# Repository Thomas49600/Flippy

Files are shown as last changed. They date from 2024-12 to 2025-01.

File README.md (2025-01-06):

# Flippy
Introducing Flippy! The all-in-one modular 3D printed electromechanical seven-segment display. Through the use of 14 electromagnets, each digit is able to quickly and mechanically display both numbers and letters. This creates a unique and satisfying display.

To build your own, check the full build instructions on Instructables: https://www.instructables.com/3D-Printed-Electromechanical-7-Segment-Display/

Or watch the YouTube video below (Link: https://youtu.be/np4NRMKOG6U)

Video Title (https://www.youtube.com/watch?v=np4NRMKOG6U)

This project falls under the CC BY-NC-SA 4.0 Licence

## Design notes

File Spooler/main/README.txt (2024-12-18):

This code was written within an hour, it is not perfect, nor is it well commented. To modify the number of windings, edit line 5:

#define TOTAL_WINDINGS 1885 //total number of loops of copper wire

You will need to experiment with this value until it results in a coil with the correct resistance.
If you are a programmer, please feel free to rewrite this code... and even share it so others can use it!

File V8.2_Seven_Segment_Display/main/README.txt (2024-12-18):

This is V8.2 of a mechanical seven-segment designed to display both words and numbers in an attractive and interesting way.
This code supports up to 8 digits and has room for expansion in the future

To upload this code do the following:
> Hold down the "flash" button on your NodeMCU
> Plug the USB connector into your computer and NodeMCU
> Wait 3 seconds
> Release the "flash" button

> Open wifi.cpp in a text editor and add your local wifi details on line 67 of wifi.cpp (make sure they are 2.4g)
> Open main.ino in Arduino IDE then compile + upload it using Arduino IDE or similar
	> Watch the following video (Credit to Brian Lough) on how to install Arduino IDE, the ESP8266 Software and the required drivers
		> https://www.youtube.com/watch?v=AFUAMVFzpWw

	> Choose the board "NodeMCU 1.0 (ESP-12E Module)"
	> Under "Tools" (top menu) choose "Flash Size - 4MB (FS:3MB OTA:~512KB)" and "Upload Speed: 115200"
	> Then hit upload (arrow button ->)

After uploading the code you will need to upload the file system
> Follow the instructions listed on this page to install the file system plugin (this is for Arduino IDE 2.2.1 or higher)
	> https://github.com/earlephilhower/arduino-littlefs-upload (Credit to earlephilhower)

> There are unfortunately a few bugs with this plugin
	> If you attempt to upload and it says "Please compile this sketch at least once", select a random board and attempt to upload the files (it will fail) then go back to your NodeMCU board and try again (it should work)
	> If you get a file path "Undefined" when you attempt to upload, close and re-open your sketch
	> If it says it cannot open serial port <port>, make sure you have closed serial monitor in all instances of Arduino IDE

> Ensure you are connected to your NodeMCU via USB and the NodeMCU is running normally (this will also likely require 12V to be plugged into the main PCB and the common anode digit connector to be disconnected)
> Then simply press [Ctrl] + [Shift] + [P], then "Upload LittleFS to Pico/ESP8266/ESP32"

After restarting your NodeMCU (either by disconnecting and reconnecting power or the RST button) you can now access the main page at "flippy.local" in a web browser on the same wifi network as you connected the device to
Sometimes due to lag the pages may fail to properly load, if this happens, refresh the webpage and it should work.
The webpages are intended for computers so if you wish to use them on your phone, simply select "desktop site" in your browser.

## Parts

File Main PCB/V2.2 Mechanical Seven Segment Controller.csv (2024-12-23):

Id | Designator | Footprint | Quantity | Designation | Supplier and ref
1 | R3,R2 | R_Axial_DIN0207_L6.3mm_D2.5mm_P7.62mm_Horizontal | 2 | 10k
2 | U6,U4,U2 | 16_Pin_DIL_IC_Socket | 3 | 74HC595
3 | K4,K2,K8,K5,K1,K3,K6,K7 | Relay_SPST_Altronics_S4252B | 8 | Relay 12V DC
4 | C6,C7,C8,C9,C5,C4,C2,C10 | C_Disc_D4.3mm_W1.9mm_P5.00mm | 8 | 0.1uf
5 | J11 | 3_Way_Screw_Terminal_Altronics_(P2033B) | 1 | MAIN POWER TERMINAL
6 | U3,U1,U5 | 18_Pin_DIL_IC_Socket | 3 | ULN2803A
7 | D3,D4,D1,D2,D7,D5,D6,D8 | D_DO-41_SOD81_P10.16mm_Horizontal | 8 | 1N4004
8 | ,,, |  | 4
9 | F1 | PinHeader_1x02_P2.54mm_Vertical | 1 | Fuse
10 | U7 | TO255P1020X450X1968-3 | 1 | LD1117V33
11 | A1 | SEEED_113990105 | 1 | Node MCU ESP8266
12 | J8 | PinHeader_1x08_P2.54mm_Vertical | 1 | Digit Connectors (+ve)
13 | J4 | PinHeader_1x03_P2.54mm_Vertical | 1 | Spare 3.3V
14 | C3 | CP_Radial_D5.0mm_P2.00mm | 1 | 10uf
15 | J9,J6 | PinHeader_1x15_P2.54mm_Vertical | 2 | ESP8266 Extra Pins
16 | J10 | PinHeader_1x05_P2.54mm_Vertical | 1 | Shift Register Expantion Ports
17 | R1 | R_Axial_DIN0207_L6.3mm_D2.5mm_P7.62mm_Horizontal | 1 | 220
18 | J7 | PinHeader_1x08_P2.54mm_Vertical | 1 | White Seg Conn (-ve)
19 | J1 | PinHeader_1x03_P2.54mm_Vertical | 1 | Spare GND
20 | J5 | PinHeader_1x08_P2.54mm_Vertical | 1 | Black Seg Conn (-ve)
21 | J2 | PinHeader_1x03_P2.54mm_Vertical | 1 | Spare VDC
22 | D9 | LED_D5.0mm | 1 | PWR_LED
23 | C1 | CP_Radial_D10.0mm_P5.00mm | 1 | 100uf
24 | J3 | PinHeader_1x03_P2.54mm_Vertical | 1 | Spare 5V

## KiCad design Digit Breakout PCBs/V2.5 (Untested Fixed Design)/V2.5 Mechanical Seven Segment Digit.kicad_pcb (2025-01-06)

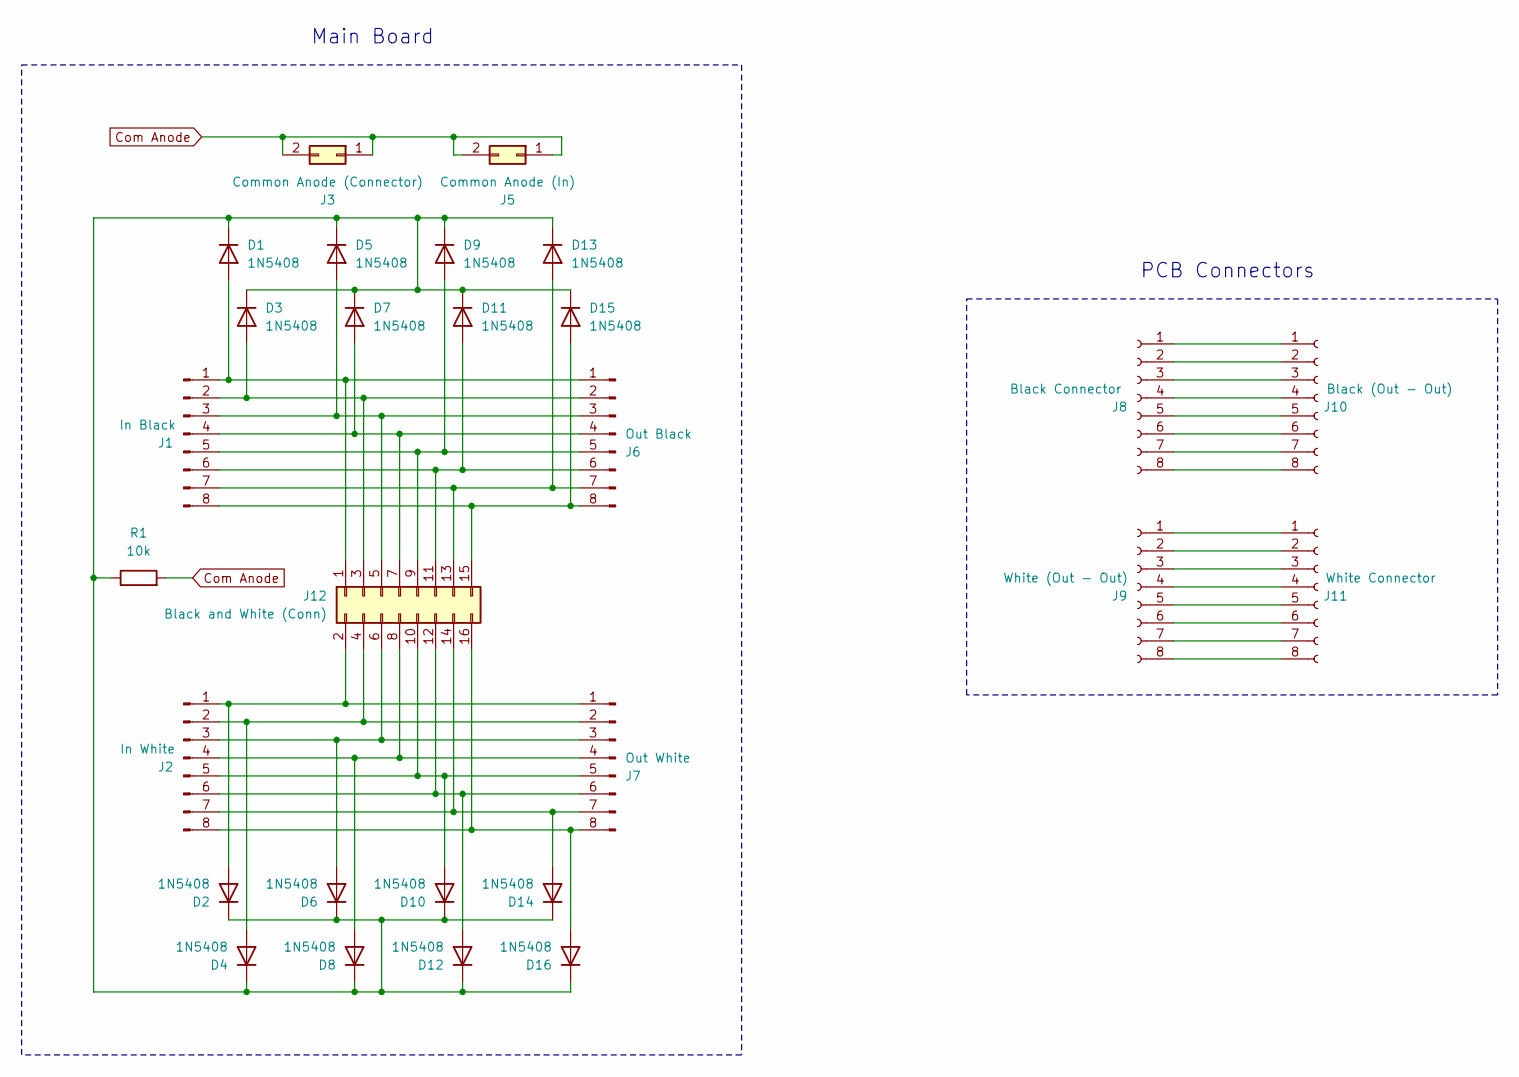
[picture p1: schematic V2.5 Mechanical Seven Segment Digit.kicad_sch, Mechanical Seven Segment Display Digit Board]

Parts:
D1, D2, D3, D4, D5, D6, D7, D8, D9, D10, D11, D12, D13, D14, D15, D16: 1N5408; D_DO-201AD_P15.24mm_Horizontal
J1: In Black; PinSocket_1x08_P2.54mm_Vertical
J2: In White; PinSocket_1x08_P2.54mm_Vertical
J3: Common Anode (Connector); PinSocket_2x01_P2.54mm_Vertical
J5: Common Anode (In); PinSocket_2x01_P2.54mm_Vertical
J6: Out Black; PinSocket_1x08_P2.54mm_Vertical
J7: Out White; PinSocket_1x08_P2.54mm_Vertical
J8: Black Connector; PinSocket_1x08_P2.54mm_Vertical
J9: White (Out - Out); PinSocket_1x08_P2.54mm_Vertical
J10: Black (Out - Out); PinSocket_1x08_P2.54mm_Vertical
J11: White Connector; PinSocket_1x08_P2.54mm_Vertical
J12: Black and White (Conn); PinSocket_2x08_P2.54mm_Vertical
R1: 10k; R_Axial_DIN0207_L6.3mm_D2.5mm_P7.62mm_Horizontal

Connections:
Com Anode: J3.1, J3.2, J5.1, J5.2, R1.2
unnamed: D1.2 (A), J1.1, J6.1, J12.1
unnamed: D1.1 (K), D2.1 (K), D3.1 (K), D4.1 (K), D5.1 (K), D6.1 (K), D7.1 (K), D8.1 (K), D9.1 (K), D10.1 (K), D11.1 (K), D12.1 (K), D13.1 (K), D14.1 (K), D15.1 (K), D16.1 (K), R1.1
unnamed: D2.2 (A), J2.1, J7.1, J12.2
unnamed: D3.2 (A), J1.2, J6.2, J12.3
unnamed: D4.2 (A), J2.2, J7.2, J12.4
unnamed: D5.2 (A), J1.3, J6.3, J12.5
unnamed: D6.2 (A), J2.3, J7.3, J12.6
unnamed: D7.2 (A), J1.4, J6.4, J12.7
unnamed: D8.2 (A), J2.4, J7.4, J12.8
unnamed: D9.2 (A), J1.5, J6.5, J12.9
unnamed: D10.2 (A), J2.5, J7.5, J12.10
unnamed: D11.2 (A), J1.6, J6.6, J12.11
unnamed: D12.2 (A), J2.6, J7.6, J12.12
unnamed: D13.2 (A), J1.7, J6.7, J12.13
unnamed: D14.2 (A), J2.7, J7.7, J12.14
unnamed: D15.2 (A), J1.8, J6.8, J12.15
unnamed: D16.2 (A), J2.8, J7.8, J12.16
unnamed: J8.1, J10.1
unnamed: J8.2, J10.2
unnamed: J8.3, J10.3
unnamed: J8.4, J10.4
unnamed: J8.5, J10.5
unnamed: J8.6, J10.6
unnamed: J8.7, J10.7
unnamed: J8.8, J10.8
unnamed: J9.1, J11.1
unnamed: J9.2, J11.2
unnamed: J9.3, J11.3
unnamed: J9.4, J11.4
unnamed: J9.5, J11.5
unnamed: J9.6, J11.6
unnamed: J9.7, J11.7
unnamed: J9.8, J11.8

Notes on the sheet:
Main Board
PCB Connectors

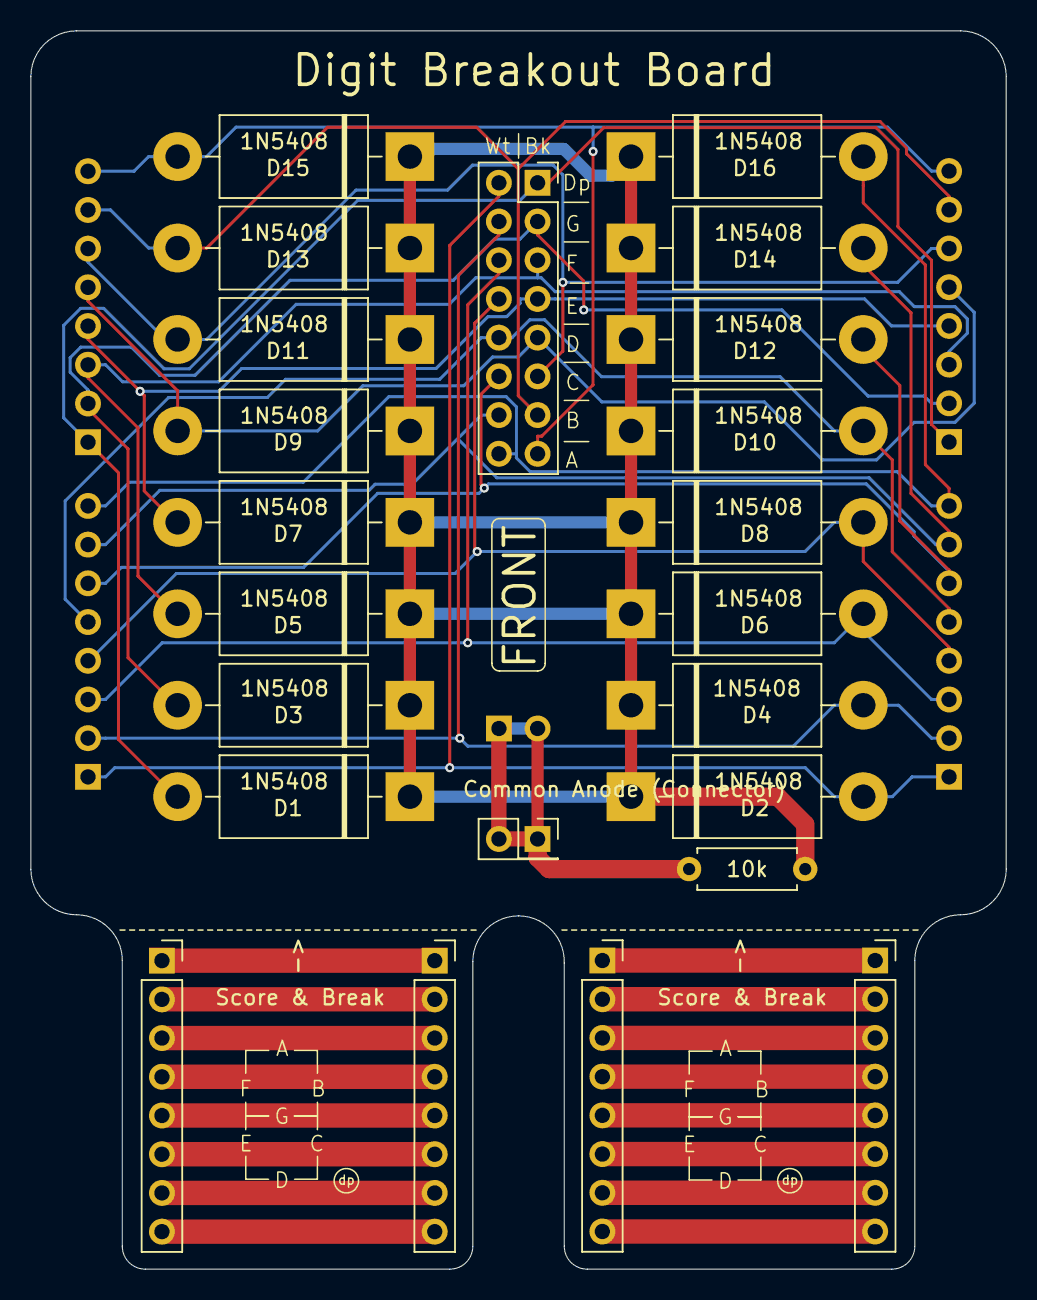
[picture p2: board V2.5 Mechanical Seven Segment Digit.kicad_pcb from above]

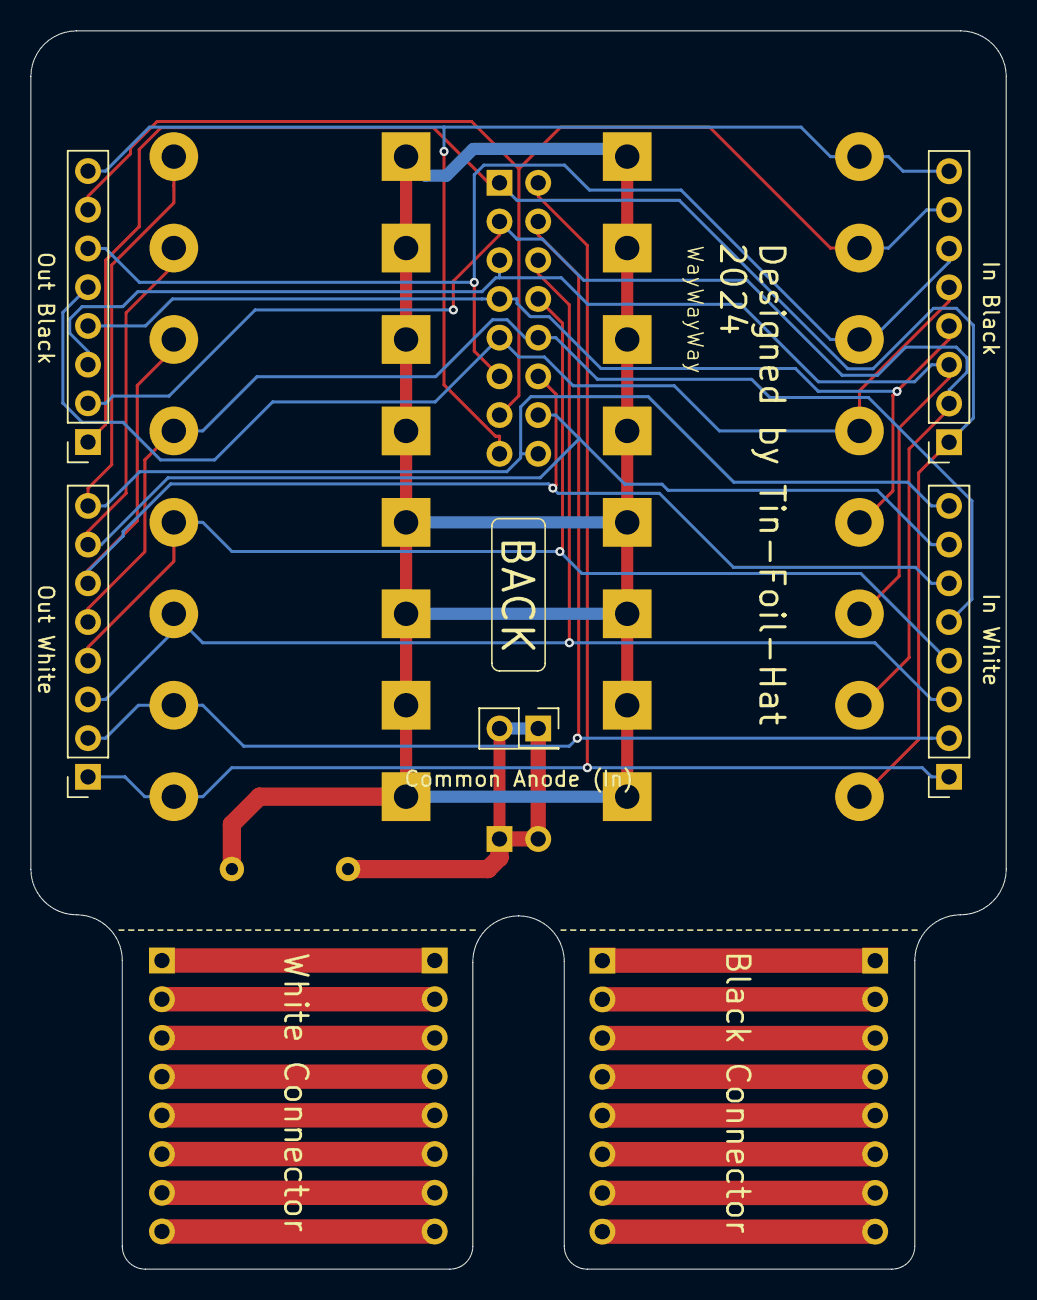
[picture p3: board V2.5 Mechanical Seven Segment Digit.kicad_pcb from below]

Board: 2 copper layers, 64.0 x 81.3 mm, 28 parts (5 on the bottom side), 34 nets.

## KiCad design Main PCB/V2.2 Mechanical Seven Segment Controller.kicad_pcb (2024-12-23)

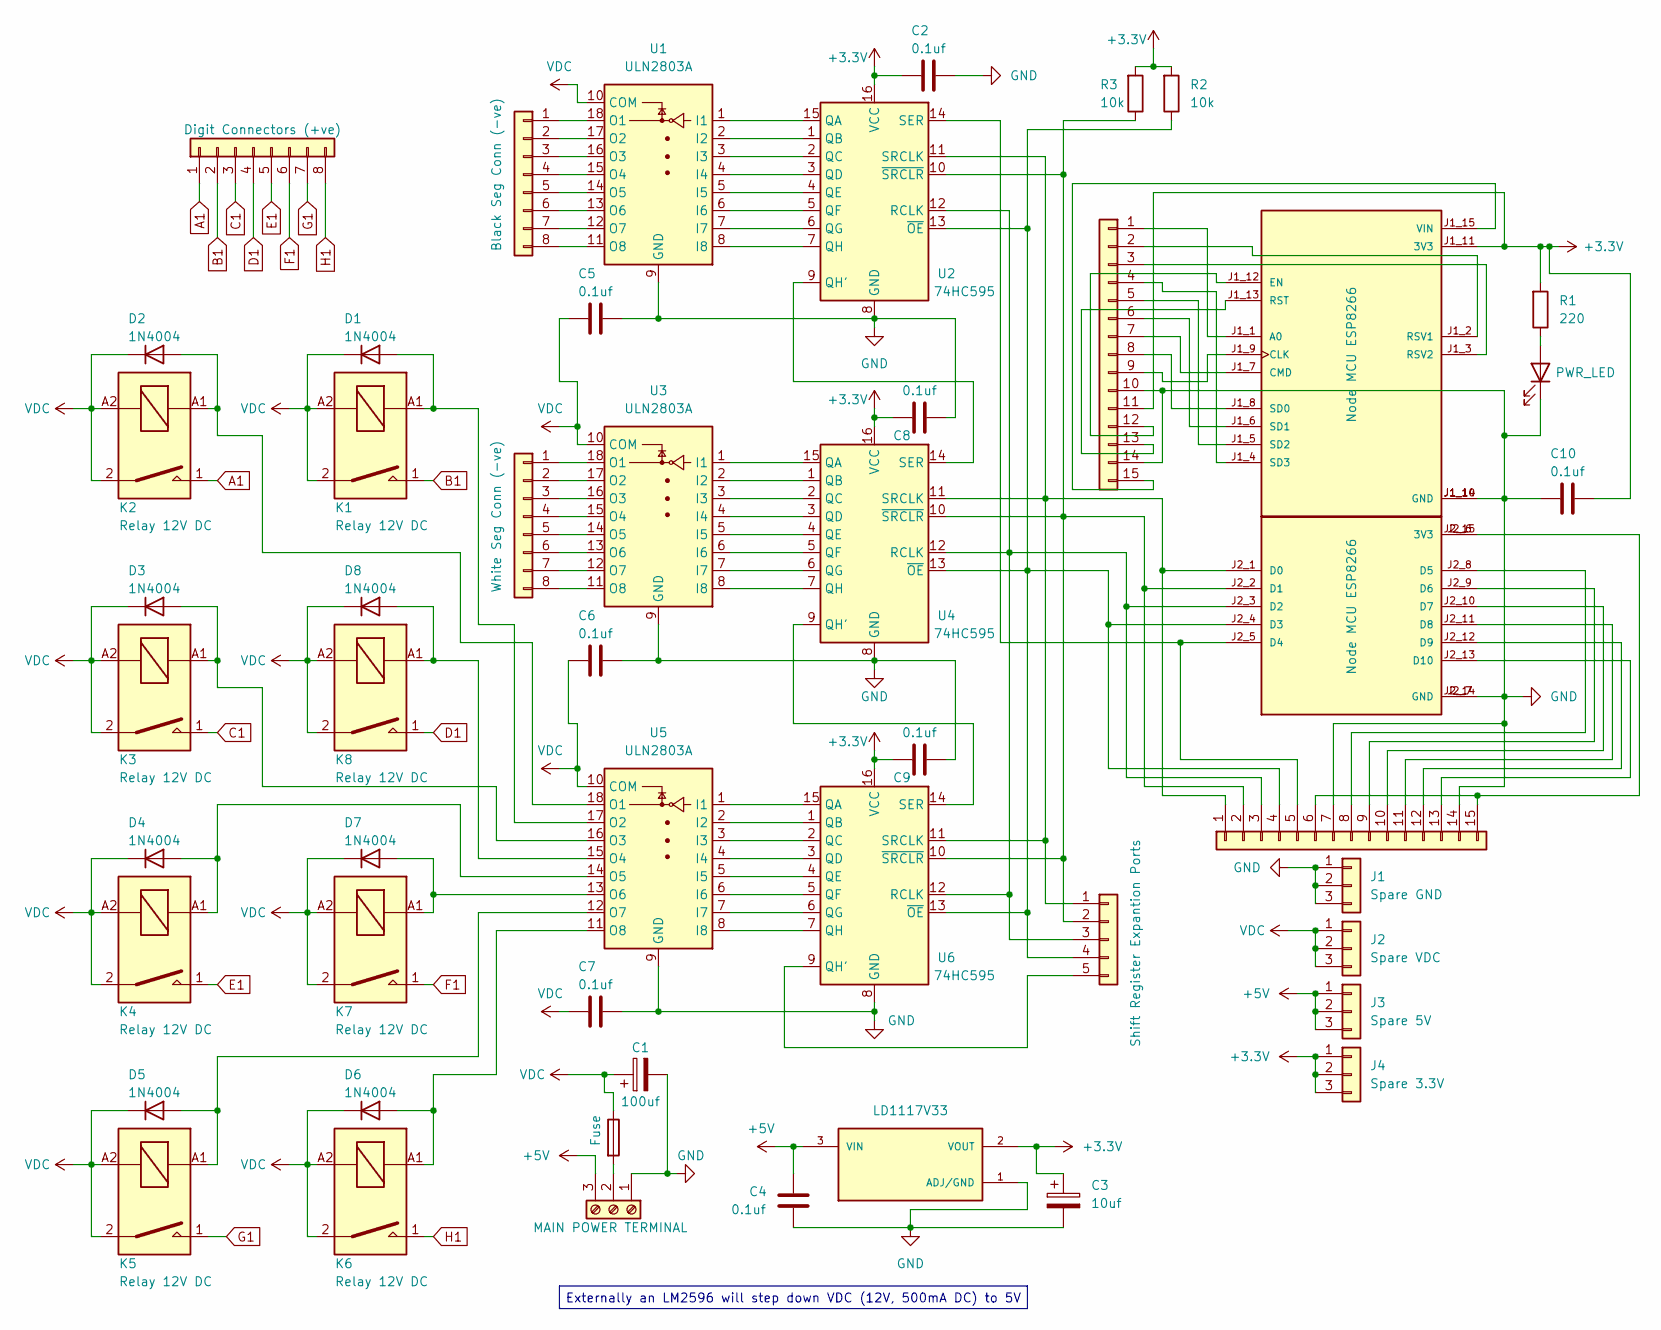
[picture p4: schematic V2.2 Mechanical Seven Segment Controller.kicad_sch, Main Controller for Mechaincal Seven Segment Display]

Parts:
A1: Node MCU ESP8266; SEEED_113990105; PARTREV N/A
C1: 100uf; CP_Radial_D10.0mm_P5.00mm
C2, C4, C5, C6, C7, C8, C9, C10: 0.1uf; C_Disc_D4.3mm_W1.9mm_P5.00mm
C3: 10uf; CP_Radial_D5.0mm_P2.00mm
D1, D2, D3, D4, D5, D6, D7, D8: 1N4004; D_DO-41_SOD81_P10.16mm_Horizontal
D9: PWR_LED; LED_D5.0mm
F1: Fuse; PinHeader_1x02_P2.54mm_Vertical
J1: Spare GND; PinHeader_1x03_P2.54mm_Vertical
J2: Spare VDC; PinHeader_1x03_P2.54mm_Vertical
J3: Spare 5V; PinHeader_1x03_P2.54mm_Vertical
J4: Spare 3.3V; PinHeader_1x03_P2.54mm_Vertical
J5: Black Seg Conn (-ve); PinHeader_1x08_P2.54mm_Vertical
J6, J9: ESP8266 Extra Pins; PinHeader_1x15_P2.54mm_Vertical
J7: White Seg Conn (-ve); PinHeader_1x08_P2.54mm_Vertical
J8: Digit Connectors (+ve); PinHeader_1x08_P2.54mm_Vertical
J10: Shift Register Expantion Ports; PinHeader_1x05_P2.54mm_Vertical
J11: MAIN POWER TERMINAL; 3_Way_Screw_Terminal_Altronics_(P2033B)
K1, K2, K3, K4, K5, K6, K7, K8: Relay 12V DC; Relay_SPST_Altronics_S4252B
R1: 220; R_Axial_DIN0207_L6.3mm_D2.5mm_P7.62mm_Horizontal
R2, R3: 10k; R_Axial_DIN0207_L6.3mm_D2.5mm_P7.62mm_Horizontal
U1, U3, U5: ULN2803A; 18_Pin_DIL_IC_Socket
U2, U4, U6: 74HC595; 16_Pin_DIL_IC_Socket
U7: LD1117V33; TO255P1020X450X1968-3; PARTREV 37

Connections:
+3.3V: A1.J1_11 (3V3), C2.2, C3.1, C8.2, C9.2, C10.1, J4.1, J4.2, J4.3, J6.11, R1.2, R2.2, R3.2, U2.16 (VCC), U4.16 (VCC), U6.16 (VCC), U7.2 (VOUT)
+5V: C4.1, J3.1, J3.2, J3.3, J11.3, U7.3 (VIN)
A1: J8.1, K2.1
B1: J8.2, K1.1
C1: J8.3, K3.1
D1: J8.4, K8.1
E1: J8.5, K4.1
F1: J8.6, K7.1
G1: J8.7, K5.1
GND: A1.J1_10 (GND), A1.J1_14 (GND), A1.J2_7 (GND), A1.J2_14 (GND), C1.2, C2.1, C3.2, C4.2, C5.1, C6.1, C7.1, C8.1, C9.1, C10.2, D9.1 (K), J1.1, J1.2, J1.3, J6.10, J6.14, J9.7, J9.14, J11.1, U1.9 (GND), U2.8 (GND), U3.9 (GND), U4.8 (GND), U5.9 (GND), U6.8 (GND), U7.1 (ADJ/GND)
H1: J8.8, K6.1
unnamed: A1.J1_1 (A0), J6.1
unnamed: A1.J1_9 (CLK), J6.9
unnamed: A1.J1_7 (CMD), J6.7
unnamed: A1.J1_12 (EN), J6.12
unnamed: A1.J1_13 (RST), J6.13
unnamed: A1.J1_2 (RSV1), J6.2
unnamed: A1.J1_3 (RSV2), J6.3
unnamed: A1.J1_8 (SD0), J6.8
unnamed: A1.J1_6 (SD1), J6.6
unnamed: A1.J1_5 (SD2), J6.5
unnamed: A1.J1_4 (SD3), J6.4
unnamed: A1.J1_15 (VIN), J6.15
unnamed: A1.J2_1 (D0), J9.1, J10.1, U2.11 (SRCLK), U4.11 (SRCLK), U6.11 (SRCLK)
unnamed: A1.J2_2 (D1), J9.2, J10.2, R3.1, U2.10 (~SRCLR), U4.10 (~SRCLR), U6.10 (~SRCLR)
unnamed: A1.J2_3 (D2), J9.3, J10.3, U2.12 (RCLK), U4.12 (RCLK), U6.12 (RCLK)
unnamed: A1.J2_4 (D3), J9.4, J10.4, R2.1, U2.13 (~OE), U4.13 (~OE), U6.13 (~OE)
unnamed: A1.J2_5 (D4), J9.5, U2.14 (SER)
unnamed: A1.J2_8 (D5), J9.8
unnamed: A1.J2_9 (D6), J9.9
unnamed: A1.J2_10 (D7), J9.10
unnamed: A1.J2_11 (D8), J9.11
unnamed: A1.J2_12 (D9), J9.12
unnamed: A1.J2_13 (D10), J9.13
unnamed: D1.2 (A), K1.A1, U5.17 (O2)
unnamed: D2.2 (A), K2.A1, U5.18 (O1)
unnamed: D3.2 (A), K3.A1, U5.16 (O3)
unnamed: D4.2 (A), K4.A1, U5.14 (O5)
unnamed: D5.2 (A), K5.A1, U5.12 (O7)
unnamed: D6.2 (A), K6.A1, U5.11 (O8)
unnamed: D7.2 (A), K7.A1, U5.13 (O6)
unnamed: D8.2 (A), K8.A1, U5.15 (O4)
unnamed: D9.2 (A), R1.1
unnamed: J5.1, U1.18 (O1)
unnamed: J5.2, U1.17 (O2)
unnamed: J5.3, U1.16 (O3)
unnamed: J5.4, U1.15 (O4)
unnamed: J5.5, U1.14 (O5)
unnamed: J5.6, U1.13 (O6)
unnamed: J5.7, U1.12 (O7)
unnamed: J5.8, U1.11 (O8)
unnamed: J7.1, U3.18 (O1)
unnamed: J7.2, U3.17 (O2)
unnamed: J7.3, U3.16 (O3)
unnamed: J7.4, U3.15 (O4)
unnamed: J7.5, U3.14 (O5)
unnamed: J7.6, U3.13 (O6)
unnamed: J7.7, U3.12 (O7)
unnamed: J7.8, U3.11 (O8)
unnamed: A1.J2_6 (3V3), A1.J2_15 (3V3), J9.6, J9.15
unnamed: J10.5, U6.9 (QH')
unnamed: F1.2, J11.2
unnamed: U1.1 (I1), U2.15 (QA)
unnamed: U1.2 (I2), U2.1 (QB)
unnamed: U1.3 (I3), U2.2 (QC)
unnamed: U1.4 (I4), U2.3 (QD)
unnamed: U1.5 (I5), U2.4 (QE)
unnamed: U1.6 (I6), U2.5 (QF)
unnamed: U1.7 (I7), U2.6 (QG)
unnamed: U1.8 (I8), U2.7 (QH)
unnamed: U2.9 (QH'), U4.14 (SER)
unnamed: U3.1 (I1), U4.15 (QA)
unnamed: U3.2 (I2), U4.1 (QB)
unnamed: U3.3 (I3), U4.2 (QC)
unnamed: U3.4 (I4), U4.3 (QD)
unnamed: U3.5 (I5), U4.4 (QE)
unnamed: U3.6 (I6), U4.5 (QF)
unnamed: U3.7 (I7), U4.6 (QG)
unnamed: U3.8 (I8), U4.7 (QH)
unnamed: U4.9 (QH'), U6.14 (SER)
unnamed: U5.1 (I1), U6.15 (QA)
unnamed: U5.2 (I2), U6.1 (QB)
unnamed: U5.3 (I3), U6.2 (QC)
unnamed: U5.4 (I4), U6.3 (QD)
unnamed: U5.5 (I5), U6.4 (QE)
unnamed: U5.6 (I6), U6.5 (QF)
unnamed: U5.7 (I7), U6.6 (QG)
unnamed: U5.8 (I8), U6.7 (QH)
VDC: C1.1, C5.2, C6.2, C7.2, D1.1 (K), D2.1 (K), D3.1 (K), D4.1 (K), D5.1 (K), D6.1 (K), D7.1 (K), D8.1 (K), F1.1, J2.1, J2.2, J2.3, K1.2, K1.A2, K2.2, K2.A2, K3.2, K3.A2, K4.2, K4.A2, K5.2, K5.A2, K6.2, K6.A2, K7.2, K7.A2, K8.2, K8.A2, U1.10 (COM), U3.10 (COM), U5.10 (COM)

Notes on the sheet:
Externally an LM2596 will step down VDC (12V, 500mA DC) to 5V

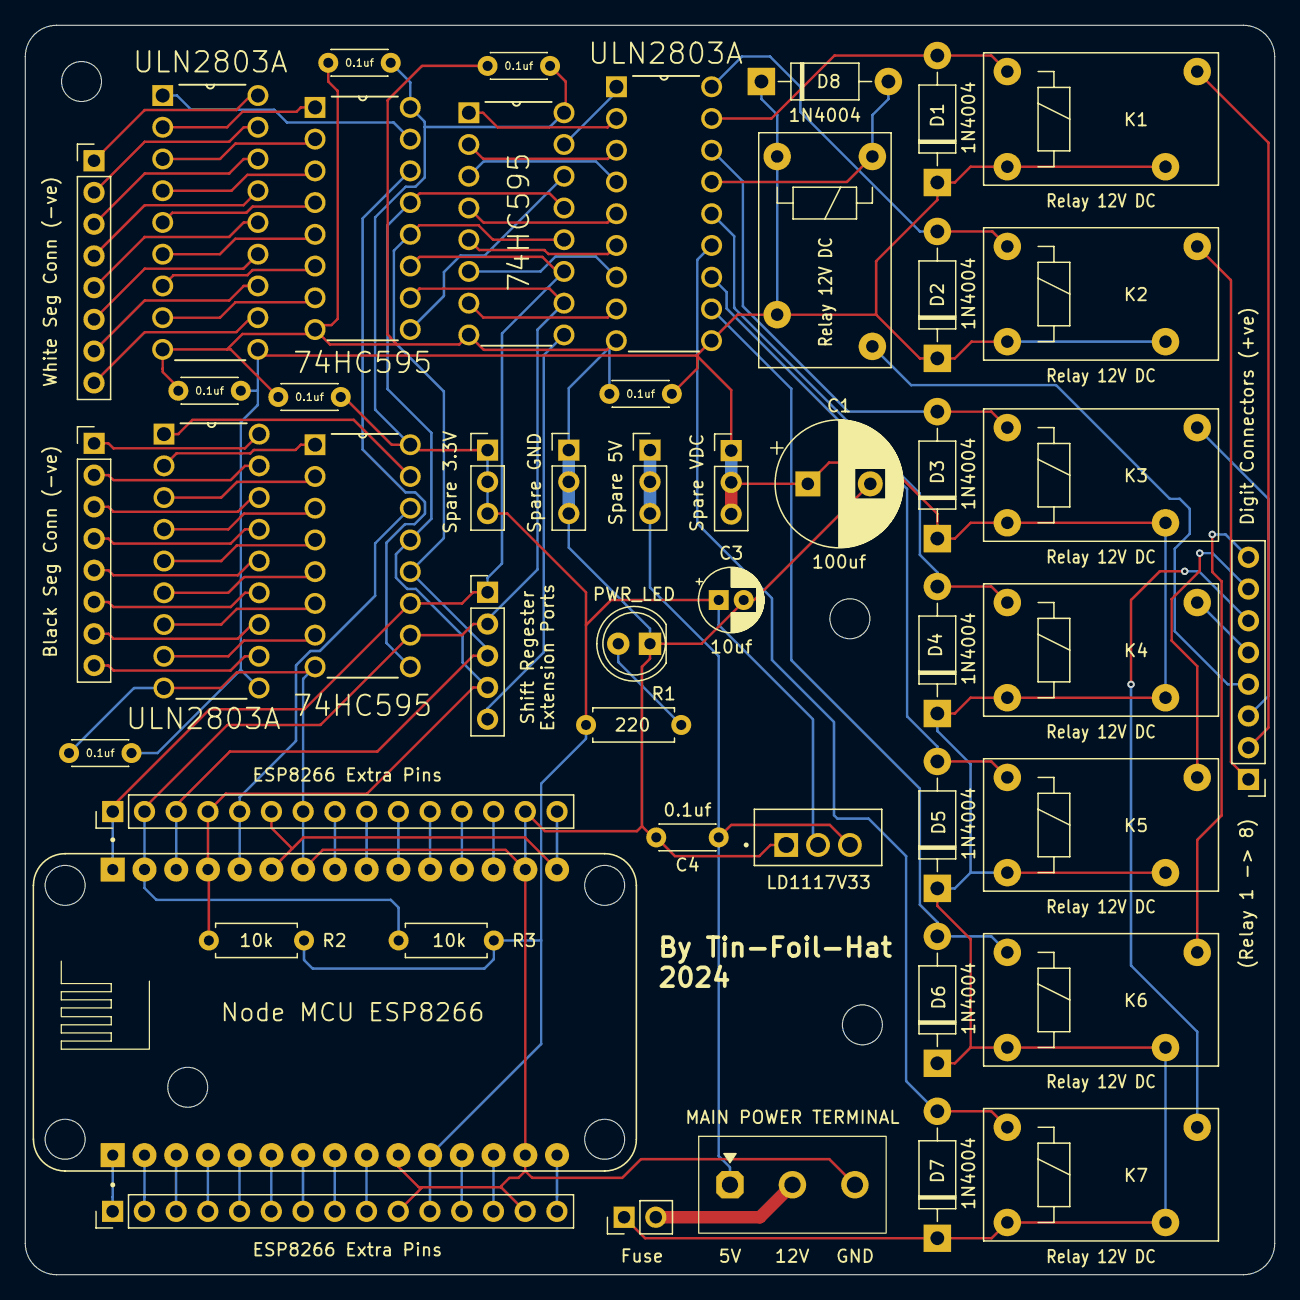
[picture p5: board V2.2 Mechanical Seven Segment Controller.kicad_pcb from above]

Board: 2 copper layers, 100.0 x 100.0 mm, 49 parts (0 on the bottom side), 89 nets.

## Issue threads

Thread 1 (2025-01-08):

Missing drill file in fixed digit board.

mypaxa00, 2025-01-08:
There is no drill file for fixed 2.5 version of digit board. Is it the same as 2.4, or could you please add missing file?

Thomas49600, 2025-01-08:
How do you know they're missing? I tried uploading them to PCBWay and it seemed to work? If you still have issues I'll try uploading all the files again. By drill files do you mean for the THT components or for bolt holes?

mypaxa00, 2025-01-08:
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
I'm not much into pcb manufacturing.
Here is the review response from the PCBWay.

Thomas49600, 2025-01-08:
Ok very odd... I will delete the current files re-export and upload them. I will try uploading the new ones to PCBWay again myself.

Thomas49600, 2025-01-09:
New ones are uploaded! Let me know if you have any issues

mypaxa00, 2025-01-09:
Looks like it is fine now, I was able to order the PCB. Thank you for your support here.

Closed 2025-01-09.

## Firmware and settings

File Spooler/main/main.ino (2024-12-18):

#include <Servo.h>

Servo myservo;

#define TOTAL_WINDINGS 1885 //total number of loops of copper wire
#define MAX_SERVO 86 // adjust to set the max servo angle
#define MIN_SERVO 10 // adjust to set the min servo angle
#define BASE_SERVO_FACTOR 4 // the basic speed of the servo moving

int stepCount = 0; // Counter to keep track of steps
int servoPos = MIN_SERVO; // Starting position of the servo
bool movingDown = true; // Flag to track direction of servo movement

/*
>> Make sure servo and motor are on separate timers <<
Timer0: Pins 5 and 6
Timer1: Pins 9 and 10
Timer2: Pins 3 and 11

The above is for an Arduino UNO
*/

// Define the pin numbers
const int enPin = 11;   // Enable pin for motor
const int in1Pin = 4;   // Input pin 1 for motor
const int in2Pin = 3;   // Input pin 2 for motor
const int irSensorPin = 2; // IR sensor pin

volatile unsigned long pulseCount = 0; // Counter for IR sensor pulses
unsigned long lastPulseTime = 0; // Time of the last detected pulse
unsigned long debounceDelay = 1.5; // Debounce delay in milliseconds

void setup() {
  // Set pin modes
  pinMode(enPin, OUTPUT);
  pinMode(in1Pin, OUTPUT);
  pinMode(in2Pin, OUTPUT);
  pinMode(irSensorPin, INPUT);
  
  // Initialize motor direction
  digitalWrite(in1Pin, HIGH);
  digitalWrite(in2Pin, LOW);
  
  // Attach interrupt to the IR sensor pin
  attachInterrupt(digitalPinToInterrupt(irSensorPin), countPulse, RISING);

  myservo.attach(9); // Attach the servo to pin 9
  myservo.write(MIN_SERVO);
  
  Serial.begin(9600); // Initialize serial communication for debugging
}

float mapFloat(float x, float in_min, float in_max, float out_min, float out_max) {
  return (x - in_min) * (out_max - out_min) / (in_max - in_min) + out_min;
}

void loop() {
  pulseCount = 0; // Reset pulse count

  int delayTime = 6000;
  int steps = 100; // Number of steps to change the speed
  int stepDelay = delayTime / steps; // Time for each step

  // Accelerate to full speed over X seconds
  for (int i = 0; i <= steps; i++) {
    Serial.println(pulseCount);
    int speed = map(i, 0, steps, 40, 255); // Map step to PWM value (min-255)
    analogWrite(enPin, speed); // Set motor speed
    delay(stepDelay); // Wait for the next step

    // Move the servo during acceleration
    if (stepCount % 2 == 0) {
      if (movingDown) {
        servoPos--; // Move the servo down
        if (servoPos <= MIN_SERVO) {
          movingDown = false; // Change direction when reaching MIN_SERVO
        }
      } else {
        servoPos++; // Move the servo up
        if (servoPos >= MAX_SERVO) {
          movingDown = true; // Change direction when reaching MAX_SERVO
        }
      }
      myservo.write(servoPos); // Move the servo to the new position
    }
    stepCount++;
  }

  // Rotate the motor X number of times
  unsigned long targetPulses = TOTAL_WINDINGS - 200;
  while (pulseCount < targetPulses) {
    Serial.println(pulseCount);
    /*
    Serial.print(2);
    Serial.print(", ");
    Serial.print(10);
    Serial.print(", ");
    Serial.println(mapFloat(servoPos, MIN_SERVO, MAX_SERVO, 0, 3.14159265359));
    */
    delay(2); // speed control of motor

    int mod_factor = BASE_SERVO_FACTOR*sin(mapFloat(servoPos, MIN_SERVO, MAX_SERVO, 0, 3.14159265359));
    if (mod_factor < 2) {
      mod_factor = 2;
    }
    // Move the servo while rotating
    if (stepCount % mod_factor == 0) { // 0.01745329251 = pi/180, 0.03490658503 = 2pi/180 = pi/90
      if (movingDown) {
        servoPos--; // Move the servo down
        if (servoPos <= MIN_SERVO) {
          movingDown = false; // Change direction when reaching MIN_SERVO
        }
      } else {
        servoPos++; // Move the servo up
        if (servoPos >= MAX_SERVO) {
          movingDown = true; // Change direction when reaching MAX_SERVO
        }
      }
      myservo.write(servoPos); // Move the servo to the new position
    }
    stepCount++;
  }

  // Decelerate to stop over X seconds
  for (int i = steps; i >= 0; i--) {
    Serial.println(pulseCount);
    int speed = map(i, 0, steps, 0, 255); // Map step to PWM value (0-255)
    analogWrite(enPin, speed); // Set motor speed
    delay(stepDelay); // Wait for the next step

    // Move the servo during deceleration
    if (stepCount % 2 == 0) {
      if (movingDown) {
        servoPos--; // Move the servo down
        if (servoPos <= MIN_SERVO) {
          movingDown = false; // Change direction when reaching MIN_SERVO
        }
      } else {
        servoPos++; // Move the servo up
        if (servoPos >= MAX_SERVO) {
          movingDown = true; // Change direction when reaching MAX_SERVO
        }
      }
      myservo.write(servoPos); // Move the servo to the new position
    }
    stepCount++;
  }

  Serial.print("Total rotations: ");
  Serial.println(pulseCount);
  //servoPos = MIN_SERVO;
  //myservo.write(servoPos);
  delay(20000000000000); // Wait
}

// Interrupt service routine for counting IR sensor pulses
void countPulse() {
  unsigned long currentTime = millis();
  if (currentTime - lastPulseTime > debounceDelay) {
    pulseCount++;
    lastPulseTime = currentTime;
  }
}

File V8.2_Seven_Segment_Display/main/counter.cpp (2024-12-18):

#include "counter.h"

#define D0_GPIO 16  // Corresponds to D0 pin
#define D1_GPIO 5   // Corresponds to D1 pin
#define D2_GPIO 4   // Corresponds to D2 pin
#define D3_GPIO 0   // Corresponds to D3 pin
#define D4_GPIO 2   // Corresponds to D4 pin
//#define D5_GPIO 14  // Corresponds to D5 pin
//#define D6_GPIO 12  // Corresponds to D6 pin
//#define D7_GPIO 13  // Corresponds to D7 pin
//#define D8_GPIO 15  // Corresponds to D8 pin

const uint8_t latchPin = D2_GPIO; // STCP or RCLK pin D2
const uint8_t clockPin = D0_GPIO; // SHCP or SRCLK pin D0
const uint8_t dataPin = D4_GPIO; // DS or SER pin D4

const uint8_t enablePin = D3_GPIO; // OE pin D3 - only used for complex control
//const uint8_t resetPin = D1_GPIO; // CLEAR pin D1 - only used for complex control  

#define FLAP_TIME 50 // <=20 is too short of a pulse for the top or bottom digit to push the flap up
#define UP_MID_DELAY 45 // a bit of an extra time for the middle flap when pushing upwards, this is needed to avoid it 'bouncing' due to it moving much faster
#define UP_TB_DELAY 40 // same as the UP_MID_DELAY but for the top and bottom flap


/*
Define the position of white for each number 0 - 9 and blank (can also add letters etc if wanted)
Where {a, b, c, d, e, f, g, dp} corresponds to:

    --- a ---
  |           |
  f           b
  |           |
    --- g --- 
  |           |
  e           c
  |           |
    --- d ---    (dp)  -> Note dp can be a comma, colon or any other segment
*/

//white is 1, black is 0
const uint8_t digitValues[] = {
  0b11111100, // 0
  0b01100000, // 1
  0b11011010, // 2
  0b11110010, // 3
  0b01100110, // 4
  0b10110110, // 5
  0b10111110, // 6
  0b11100000, // 7
  0b11111110, // 8
  0b11110110  // 9
};

const char letterKeys[] = {'A', 'b', 'C', 'c', 'd', 'E', 'F', 'G', 'H', 'h', 'I', 'J', 'L', 'N', 'n', 'O', 'o', 'P', 'q', 'r', 'S', 't', 'U', 'u', 'y', '-'};
const uint8_t letterKeysSize = sizeof(letterKeys) / sizeof(letterKeys[0]); // total number of BITS in the array, divided by the number of bits 1 charactor has
const uint8_t letterValues[] = {
  0b11101110, // A
  0b00111110, // b
  0b10011100, // C
  0b00011010, // c
  0b01111010, // d
  0b10011110, // E
  0b10001110, // F
  0b10111100, // G
  0b01101110, // H
  0b00101110, // h
  0b01100000, // I
  0b01110000, // J
  0b00011100, // L
  0b11101100, // N
  0b00101010, // n
  0b11111100, // O
  0b00111010, // o
  0b11001110, // P
  0b11100110, // q
  0b00001010, // r
  0b10110110, // S
  0b00011110, // t
  0b01111100, // U
  0b00111000, // u
  0b01110110, // y
  0b00000010  // -
};

const uint8_t BLANK = 0b00000000; // Set all to black

// The below can be set to true or false
// It determins if the flaps are in an override mode (where even if it is white showing, it still tries to show white again)
// Or not in override mode (where if a flap is white and it wants it to be white, it just skips over it)
// Sometimes flaps may get stuck or 'bouce' meaning they're  not in the expected state, override fixes this but is slower for general performance

// Define the global variable
bool OVERRIDE_MODE = true;  // Initial value

#define TOTAL_DIGITS 8 // the total possible number of digits, unless you build an expansion board you can't exceed 8 (nothing is designed to go past 8 digits as I don't expect anyone to ever make that many)

///////////////////////////// PUBLIC FUNCTIONS /////////////////////////////
void setupCounter() {
  // Setup pins as Outputs
  pinMode(latchPin, OUTPUT);
  pinMode(clockPin, OUTPUT);
  pinMode(dataPin, OUTPUT);

  pinMode(enablePin, OUTPUT);
  //pinMode(resetPin, OUTPUT);

  // establish normal operation mode
  digitalWrite(enablePin, LOW);
  //digitalWrite(resetPin, HIGH);

  delay(100); // wait one sec as otherwise you have random issues

  // Make sure all shift regesters are set to clear.
  shiftOut(dataPin, clockPin, LSBFIRST, 0x00);
  shiftOut(dataPin, clockPin, LSBFIRST, 0x00);
  shiftOut(dataPin, clockPin, LSBFIRST, 0x00);
}

// Setter function for OVERRIDE_MODE
void setOverrideMode(bool newState) {
  OVERRIDE_MODE = newState;  // Set the value of OVERRIDE_MODE to newState
}

///////////////////////////// Counter FUNCTIONS /////////////////////////////
// CONSTRUCTOR & DESTRUCTOR
Counter::Counter(uint8_t numDigits, uint8_t startingPos) {
  validFlag = false; // assume it is invalid
  currentSequence = nullptr;  // Set the pointer to nullptr by default

  if (numDigits > 0) { // can't have negative digits
    numberOfDigits = numDigits;

    if (startingPos >= 0) { // check that the position is at least the 1st one
      if ((startingPos + numDigits - 1) <= TOTAL_DIGITS) { //check that the counter doesn't exceed the total number of digits (when shifted by the startingPos)
        startingPosition = startingPos;
        validFlag = true; // set the flag as true as it passed all checks
      
      } else {
      Serial.println("Digit overflow");
      }

    } else {
      Serial.println("Invalid starting position");
    }

  } else {
    Serial.println("Must have at least 1 digit");
  }

  
  if (validFlag == true) { // if it is valid, create the currentSequence array and clear the display
    currentSequence = new uint8_t[numberOfDigits](); // Allocate memory for the array
    
    // set all values to 255, this ensures all flaps are initally reset
    for (int i = 0; i < numberOfDigits; ++i) {
      currentSequence[i] = 255; // i.e. B11111111
    }
    
    clearDisplay(false); // will swipe from L - R
  }
}

Counter::~Counter() { // destructor
  if (currentSequence != nullptr) { // Check if the pointer is not null
    delete[] currentSequence;  // Safely delete the allocated memory
  }
}
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
